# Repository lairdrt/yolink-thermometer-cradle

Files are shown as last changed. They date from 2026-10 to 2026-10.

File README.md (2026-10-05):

# YoLink Thermometer Cradle

A parametric, 3D-printable wall-mount cradle for the **YoLink YS8017-UC** temperature sensor.

## Purpose

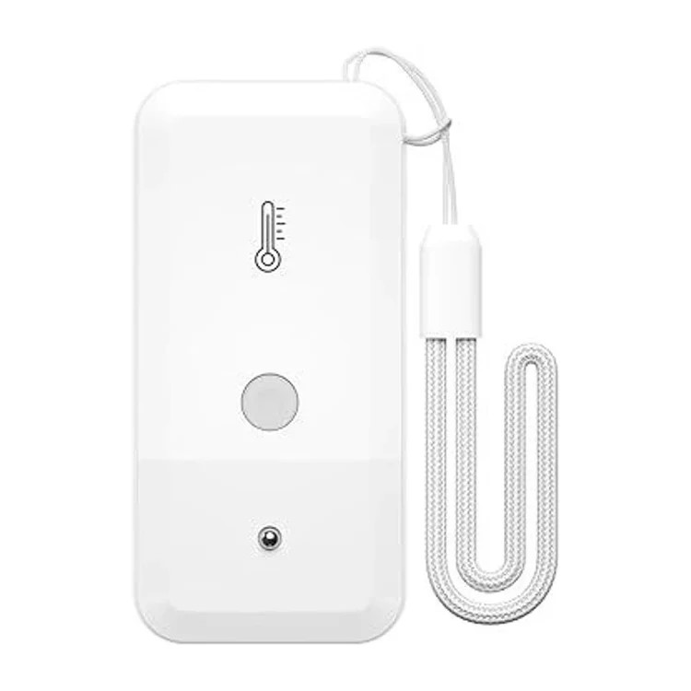
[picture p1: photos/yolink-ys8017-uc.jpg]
YoLink YS8017-UC temperature sensor


The cradle holds the sensor securely on a wall while keeping it ventilated and its front display visible.

- The sensor slides into the cradle from the top.
- The cradle is meant for indoor or sheltered locations.
- **Note:** this project does not assume the YoLink sensor is weatherproof. Check the manufacturer's rating separately before using it anywhere it could get wet.

## Status

The design has been physically prototyped. The exported STL and 3MF files match the current source geometry.

### Prototype photos

<p>
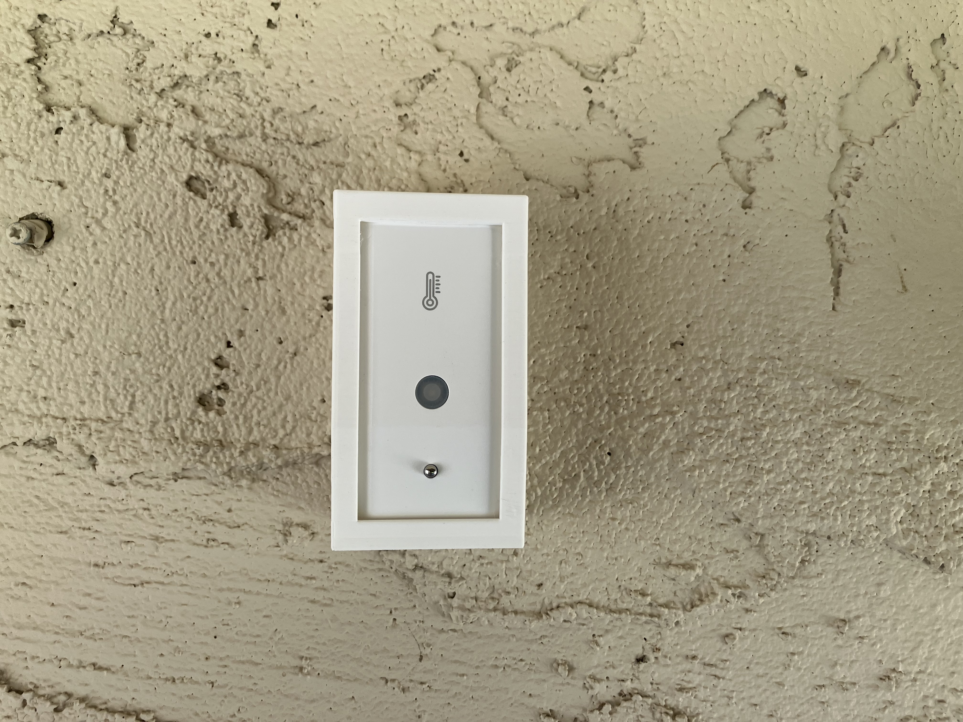
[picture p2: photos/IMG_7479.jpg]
Printed cradle holding the sensor, wall-mounted, front view
  
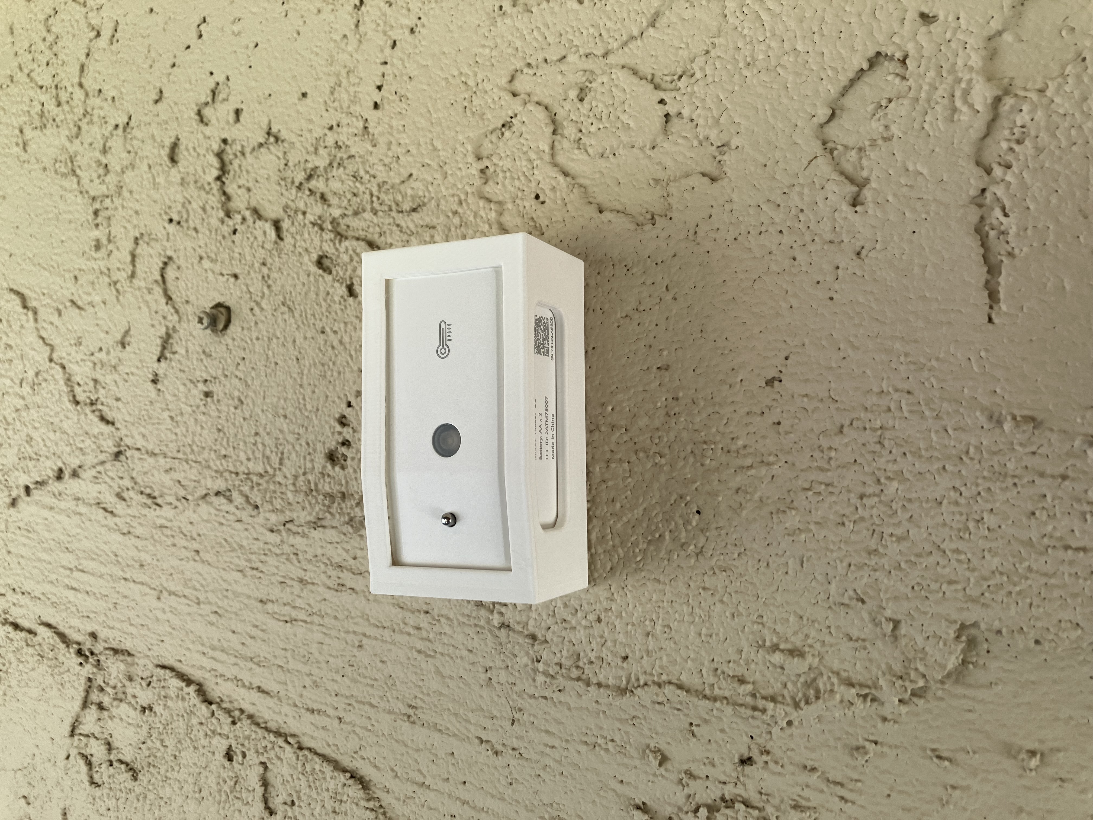
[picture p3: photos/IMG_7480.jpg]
Printed cradle holding the sensor, wall-mounted, angled view showing a side window
  
</p>

## Design and features

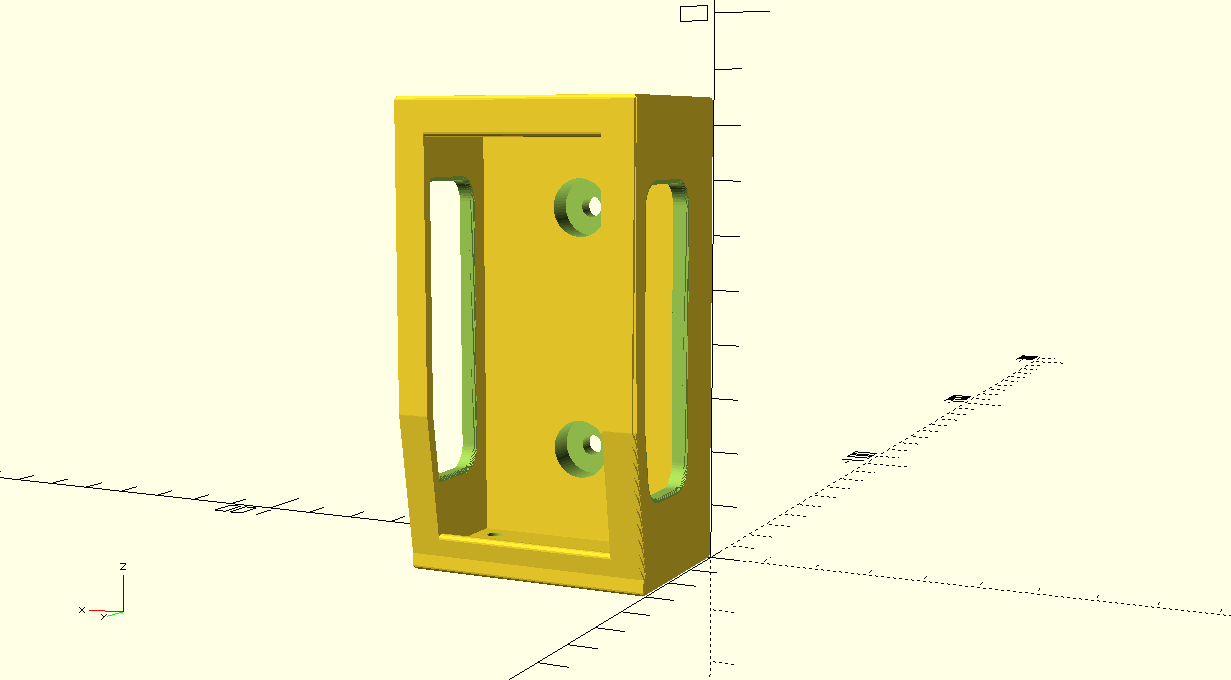
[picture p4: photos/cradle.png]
Rendered cradle model


- Open front, so the sensor's display stays visible
- Continuous left and right front retaining rails
- Bottom retaining lip
- Full-width top header that braces the front
- Asymmetric side windows for airflow:
  - the rear edge is straight and parallel to the back wall
  - the front edge follows the sensor's tapered front profile
- Four 3.0 mm drain holes through the bottom floor
- Two wall-mount screw locations, counterbored from the front

### Sensor (as measured)

| Parameter | Value |
|---|---|
| Model | YoLink YS8017-UC |
| Width | 39.0 mm |
| Height | 80.0 mm |
| Upper depth | ~24 mm |
| Lower depth | ~20 mm |
| Taper knee | 26 mm above the bottom / 54 mm below the top |

### Cradle

| Parameter | Value |
|---|---|
| Outer size | 46.2 mm W × 34.6 mm D × 85.0 mm H |
| Rear wall | 8.0 mm |
| Bottom floor | 3.0 mm |
| Side clearance | 0.6 mm per side |
| Front/profile clearance | 0.6 mm |
| Exterior edge rounding | 0.75 mm (target) |
| Drain holes | 4 × Ø3.0 mm |
| Screw locations | Z = 20 mm and Z = 65 mm, on the centreline (each 20 mm from the nearer end) |

## Mounting hardware

| Item | Specification |
|---|---|
| Screws | #6 × 1-1/2 in pan-head sheet-metal screws (2) |
| Washers | Everbilt #6 flat washer, model 800422 (2) |
| Washer OD | 9.525 mm |
| Washer thickness | 1.24 mm |
| Shank clearance hole | Ø3.9 mm |
| Washer/head counterbore | Ø10.75 mm, 5.0 mm deep |
| Material behind counterbore | 3.0 mm solid |

Screw-head dimensions vary between #6 screws, so the design does not rely on any one head height. The counterbore provides extra clearance for normal variation in #6 pan-head screw geometry.

## Printing and use

- Print upright with the bottom on the build plate.
- Verified on a Bambu Lab P1S with a 0.4 mm nozzle and 0.20 mm layer height.
- PLA/PLA+ was used successfully for prototyping and testing.
- No supports are needed in this orientation.
- The top header is a bridge of roughly 34 mm; Bambu Studio printed it as a normal bridge.
- Let the build plate cool before removing the part.
- The screw counterbores were confirmed good on the first physical print.
- Insert the sensor from the top, and check the fit before mounting the cradle permanently.

## Limitations and warnings

- Dimensions come from the one YS8017-UC unit measured for this project. Other units may vary.
- Printer accuracy and filament shrinkage can affect fit, and the front and side clearances are deliberately small.
- The drain holes are incidental. This is **not** a waterproof enclosure.
- Don't expose the sensor directly to rain or water unless the manufacturer's own rating says that's safe.
- `src/cradle.scad` is the source of truth. Regenerate the STL and 3MF exports whenever it changes.

## Development approach

The cradle is a parametric OpenSCAD model, developed through an iterative design-and-review loop:

1. ChatGPT was used to define and refine the design intent and to review the architecture.
2. Claude (Claude Code in VS Code) edited `src/cradle.scad` directly.
3. OpenSCAD's Automatic Preview gave live visual feedback. F5 was used for quick previews and F6 (CGAL render) for authoritative geometry checks.
4. Geometry was checked repeatedly with targeted boolean and probe tests.
5. Physical prototype prints were used to correct the real measurements.
6. The final STL and 3MF exports were verified against the current source geometry.

## Tools

| Tool | Use |
|---|---|
| OpenSCAD 2021.01 | Parametric CAD modelling and export |
| VS Code | Editing |
| Claude Code / Claude in VS Code | Source editing and verification assistance |
| ChatGPT | Design iteration and architecture/review |
| Bambu Studio | Slicing |
| Bambu Lab P1S, 0.4 mm nozzle | Printing |

## Repository structure

```
src/         OpenSCAD source (cradle.scad)
exports/     Print files (cradle.stl, cradle.3mf)
photos/      Product, render and prototype images
reference/   Reference CAD material (FreeCAD .FCStd)
```

## License

GNU General Public License v3.0. See [LICENSE](LICENSE).

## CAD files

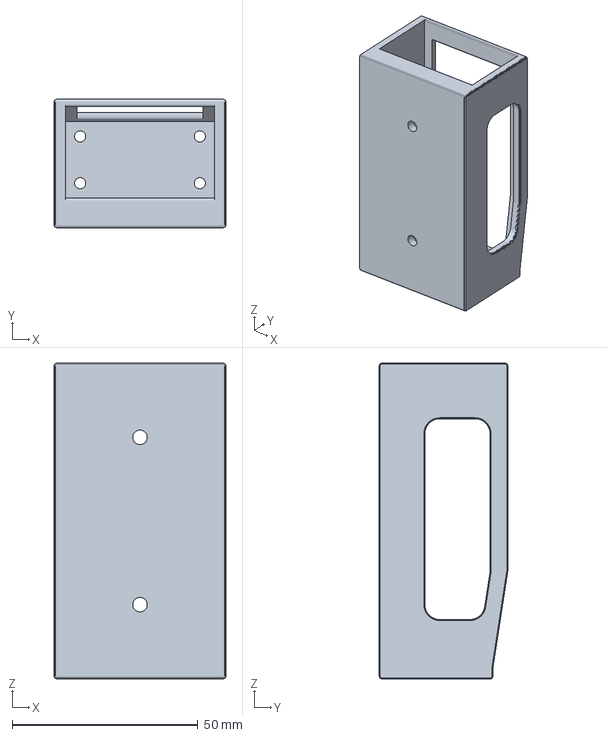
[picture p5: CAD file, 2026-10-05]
exports/cradle-p1s-print.3mf
46.2 x 34.6 x 85.0 mm

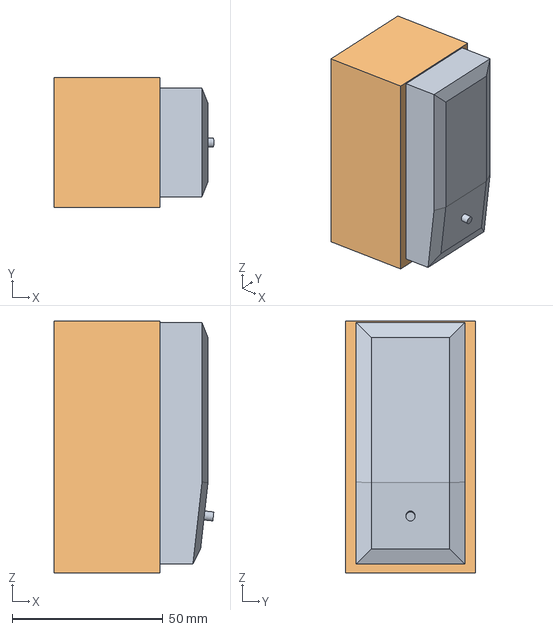
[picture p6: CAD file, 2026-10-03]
reference/yolink-cradle.FCStd
52.9 x 43.0 x 83.5 mm
Body_Model
Body_Cradle

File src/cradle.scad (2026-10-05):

$vpt = [0, 0, 45];   // viewpoint target / translation
$fn = 64;   // finer display resolution

// YoLink Thermometer Cradle
// Stage 2: basic cradle with tapered sensor profile

// ============================================================
// SENSOR DIMENSIONS
// ============================================================

sensor_width  = 39.0;
sensor_height = 80.0;

// Depth measured from rear face

sensor_depth_top    = 24;
sensor_depth_bottom = 20;

// The front taper's knee is 26.0 mm above the sensor's bottom,
// equivalently 54.0 mm down from its top.  Measured from the
// bottom, because the bottom is the seated datum: it is where the
// sensor lands on the shelf, so the knee's height above it does
// not move if the overall height is ever re-measured.

taper_height = 26.0;   // above the sensor bottom


// ============================================================
// FIT / CRADLE DIMENSIONS
// ============================================================

side_clearance  = 0.6;
depth_clearance = 0.6;

back_wall   = 8.0;
side_wall   = 3.0;
bottom_wall = 3.0;


// ============================================================
// FRONT RETENTION
//
// Two continuous vertical rails (one per side, integral with
// its side wall), one bottom front lip, and one top front header
// rail.  All of it is derived from the side profile's front edge,
// so it follows the sensor's changing front depth automatically.
// ============================================================

// How far each rail overlaps the sensor's front face, in X
rail_face_overlap = 2.5;

// How far the rails stand forward of the sensor front, in Y
rail_thickness    = 2.0;

// Bottom front lip.  Its forward projection is rail_thickness, so
// its front face is flush with the rails' and never stands proud.
front_lip_height    = 7.0;   // how far up the lip reaches in Z

// Top front header rail: the lip's counterpart across the top of
// the front opening, flush with the cradle's rim.  Same band, same
// forward projection and same full width as the lip, so the two
// read as a pair.
//
// It does not obstruct the open top.  Like the lip, it retains by
// standing in FRONT of the sensor rather than over it: the band
// lies at front_depth_at(z), which is depth_clearance ahead of the
// sensor's front face, while the sensor drops in through the
// aperture behind it.  The cradle's front edge is parallel to the
// sensor's own taper, so that gap is depth_clearance at every
// height of the travel, not just when seated.
front_header_height = front_lip_height;   // matched to the lip


// ============================================================
// WALL MOUNTING
//
// Two #6 x 1-1/2" pan-head sheet-metal screws, vertically
// aligned on the centreline, with Everbilt 800422 #6 flat
// washers (9.525 mm OD) captured in recesses counterbored into
// the FRONT face of the rear wall, so both are driven through
// the cradle's open front.
//
// No screw-head height is assumed.  The rear wall is budgeted
// as a stack instead:
//
//   back_wall 8.0 = 3.0  solid material behind the counterbore
//                 + 3.0  washer + screw-head allowance
//                 + 2.0  clearance from hardware to the sensor
//
// so the counterbore is 3.0 + 2.0 = 5.0 deep, and the material
// left behind it is back_wall - 5.0 = 3.0.  Hardware taller than
// the 3.0 mm allowance eats into the 2.0 mm of clearance rather
// than into the sensor.
// ============================================================

screw_shank_diameter   = 3.9;    // #6 shank 3.5 mm + clearance
washer_recess_diameter = 10.75;  // washer OD 9.525 + clearance

hardware_allowance = 3.0;        // washer + screw head, budgeted not measured
hardware_clearance = 2.0;        // hardware front face to sensor rear plane

washer_recess_depth = hardware_allowance + hardware_clearance;   // 5.0

// The upper screw mirrors the lower one: as far below the top as
// the lower is above the bottom.  upper_screw_z is derived from
// this below, once outer_height is known.
lower_screw_z = 20;


// ============================================================
// EXTERIOR EDGE ROUNDING
//
// Target: about 0.75 mm radius on the exposed exterior edges, to
// kill sharp printed arrises without moving any fitting surface.
//
// Every piece of this cradle is an extrusion along X of some
// (depth, height) profile, and those profiles nest, so the
// rounding is done in two cheap passes rather than with a
// whole-body minkowski():
//
//   1. Edges that RUN ALONG X - the top rim, the bottom and rear
//      perimeters, the front faces, the taper kink - are rounded
//      by a 2D morphological opening of each slab profile:
//      offset(+r) offset(-r), intersected back with the profile.
//      A true opening is always a SUBSET of its input, so it can
//      only ever remove material; no clearance can shrink and the
//      dummy sensor cannot be newly touched.  The intersection is
//      what makes that true of this one: offset() approximates
//      its disc with a round_fn-gon, and at a CONCAVE corner the
//      pair overshoots the corner by about
//      r * (sec(180/round_fn) - 1) - 0.0147 mm at r = 0.75, which
//      is 0.0147 mm of material standing in the sensor seat.
//      Small, but it is on a fit surface, and the subset property
//      is what the rest of this reasoning rests on.
//
//   2. Edges that LIE IN the X = 0 and X = outer_width planes -
//      the four long vertical corners, plus the top, bottom,
//      front and rear edges of the outer side faces - are rounded
//      by extruding the outermost slab through a short stack of
//      progressively inset slices following a true quarter round.
//      Eight slices hold the stair within 0.075 mm of the real
//      arc, well under a print layer, so it is a 0.75 mm round for
//      any practical purpose.  The slices are unioned rather than
//      hull()ed, because hull() would fill in the non-convex
//      profile.
//
// Deliberately NOT rounded: the screw shank hole and washer
// counterbore (hardware fit), the side-wall inner faces at
// X = side_wall (the 0.6 mm side clearance), the rail inner faces
// at X = rail_width (the 2.5 mm face overlap that does the
// retaining), and the bottom sensor seat - its corners are
// concave, and an opening leaves concave corners sharp.
// ============================================================

edge_round  = 0.75;
round_steps = 8;    // slices approximating each quarter round
round_fn    = 16;   // arc resolution for the small 2D rounds


// ============================================================
// SIDE WINDOWS
//
// One rounded window per side wall, for airflow and material
// reduction, centred on the SENSOR's height rather than on the
// cradle's outer height.
//
// Sensor side area, from the sensor's own tapered profile:
//
//   (20 + 24)/2 * 26  +  24 * 54  =  572 + 1296  =  1868 mm2
//
// The window is not a rectangle, and it is not a parallelogram
// either: its two long edges answer to different things.
//
//   FRONT edge - follows the cradle's own front edge, off the same
//     front_depth_at() curve the side walls and rails use, so it
//     stays window_front_gap behind that edge at every height:
//     vertical above the knee, parallel to the taper below it.
//
//   REAR edge - straight in Y and Z, parallel to the rear wall, at
//     the fixed depth window_rear_y.  Deliberately NOT derived
//     from the front taper: the rear wall does not move, so there
//     is no reason for the web behind the window to vary, and a
//     sheared rear edge only crowds that wall at the window's
//     lowest point.
//
// The window is therefore wider at the top and narrows through the
// knee region, 17.5 mm above the taper down to 15.5 mm at its
// bottom edge.  That asymmetry is the point: it is the cradle
// tapering in, not the window being pulled in.
//
// window_depth is the window's Y depth in the upper, vertical
// section.  window_front_gap is the web between the window and the
// side profile's front edge, constant at every height - the rails
// stand a further rail_thickness forward of it, so there is about
// 4.0 mm of material ahead of the window once the edge_round rim
// flare is counted.  The web behind is constant too, at
// window_rear_y - back_wall = 4.3 mm, 3.55 after the flare.
//
// Window outline 918.3 mm2 nominal = 49.2 % of the side area
// (measured off the rendered outline: 919.8 mm2).  The area is
// within 1.5 % of the 88 mm model's window; the percentage rises
// because the sensor itself is shorter.
// ============================================================

window_depth     = 17.5;   // in Y, measured horizontally
window_height    = 54.0;   // in Z
window_corner    = 4.0;    // corner radius
window_front_gap = 2.8;    // web between window and the front face
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

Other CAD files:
exports/cradle.3mf
exports/cradle.stl

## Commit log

2026-10-03 Initial verified OpenSCAD cradle design
    [cradle.3mf, cradle.scad, cradle.stl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]
2026-10-05 Baseline verified Version 2 cradle design
    Sensor 39.0 x 80.0 mm, taper knee 26 mm above sensor bottom.
    Cradle outer 46.2 x 34.6 x 85.0 mm; two wall-mount screw counterbores,
    four 3.0 mm floor drainage holes, 0.75 mm exterior edge rounding,
    side windows, top header, side rails and bottom lip.
    [cradle.3mf, cradle.stl]
2026-10-05 Baseline verified Version 3 cradle design
    - Upper wall-mount screw moved from Z 74 to Z 65, now derived as
    outer_height - lower_screw_z; the lower screw stays at Z 20.
    - Screw centres are symmetric, each 20 mm from the top/bottom.
    - STL and 3MF exports regenerated from the current source.
    - README refreshed for the current CAD render and prototype photos,
    with screw positions updated.
    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
    [cradle.3mf, cradle.scad, cradle.stl]
2026-10-05 Add prototype photos
2026-10-05 Printable P1S project
    [cradle-p1s-print.3mf]
2026-10-05 Update README prototype photos
